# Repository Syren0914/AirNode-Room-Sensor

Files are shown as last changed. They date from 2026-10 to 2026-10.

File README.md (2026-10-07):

# AirNode Room Sensor

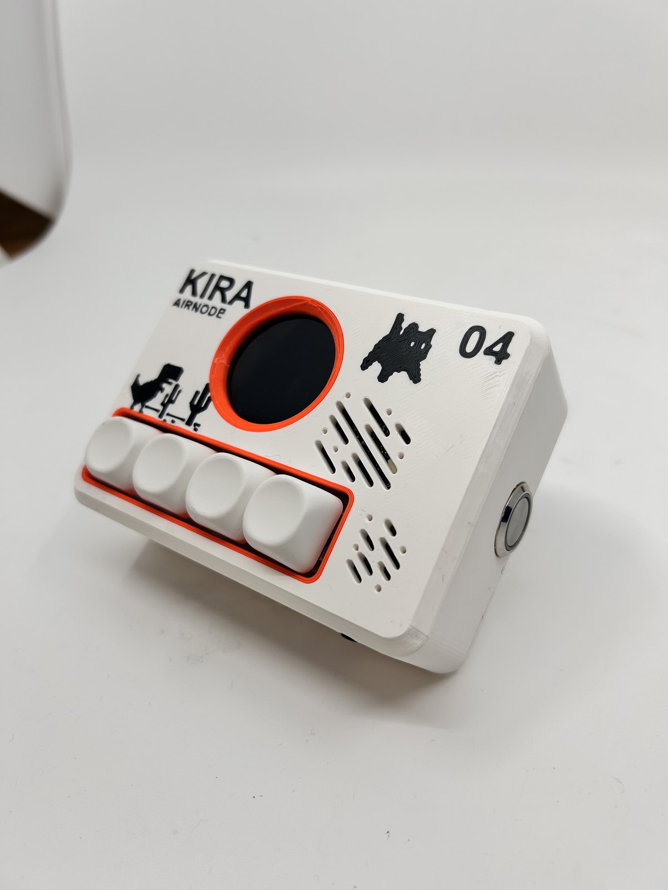
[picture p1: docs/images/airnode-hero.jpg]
AirNode prototype


> [!WARNING]
> **AirNode is an ongoing, unfinished prototype.** The PCB, enclosure, firmware, pin assignments, and documentation may change. This revision has not completed long-term validation, calibration, or product safety testing and is not production ready.

AirNode is an ESP32-C3 based indoor air-quality monitor in a compact 70 mm × 100 mm enclosure. It combines a round color display, four buttons, an audible alarm, and connections for environmental sensor modules.

## Current capabilities

- ESP32-C3 SuperMini with Wi-Fi and Bluetooth LE
- 1.28-inch round SPI TFT
- SHT40 temperature and humidity sensor
- SCD40 carbon-dioxide sensor connection
- SGP41 VOC and NOx sensor connection
- SPS30 particulate-matter sensor connection
- Back-mounted passive piezo buzzer on GPIO20
- Four buttons: Up, Down, Select, and Back
- Two-layer 70 mm × 100 mm PCB with 8 mm corner radii
- 3D-printable enclosure source

## Project status

This repository records a working prototype and the next custom PCB revision. The photographed device uses development modules and point-to-point wiring; the KiCad design consolidates those connections onto a PCB.

| Area | Status |
| --- | --- |
| Schematic ERC | Pass: 0 violations |
| PCB connectivity | Pass: 0 unconnected items |
| PCB DRC | No shorts or clearance violations; one intentional dangling-via warning at the TFT CS layer transition |
| Enclosure | Prototype printed and assembled; PCB fit still requires physical verification |
| Firmware | Working prototype shown; source has not been added to this repository yet |
| Sensor calibration | In progress |
| Production testing | Not started |

## Documentation

- [Hardware and pin assignments](docs/HARDWARE.md)
- [Assembly guide](docs/ASSEMBLY.md)
- [First power-on and validation](docs/BRINGUP.md)
- [Firmware status and requirements](docs/FIRMWARE.md)
- [Enclosure and mechanical fit](docs/ENCLOSURE.md)
- [Board-mounted USB-C power input](docs/USB-C-extension.md)
- [Bill of materials](BOM.csv)
- [Change log](CHANGELOG.md)

## Repository contents

- `Room Sensor.kicad_pro` — KiCad project
- `Room Sensor.kicad_sch` — schematic source
- `Room Sensor.kicad_pcb` — PCB layout source
- `RoomSensor_Libraries/` — project symbols and footprints
- `V.2.3mf` — printable enclosure source
- `Room Sensor.step` — PCB 3D export
- `BOM.csv` — bill of materials
- `manufacturing/gerbers/` — fabrication outputs for the current revision

Open `Room Sensor.kicad_pro` with KiCad 10 or newer. Review the schematic, PCB, and fabrication files together before ordering boards because the project remains under development.

## Prototype gallery

### Assembled enclosure

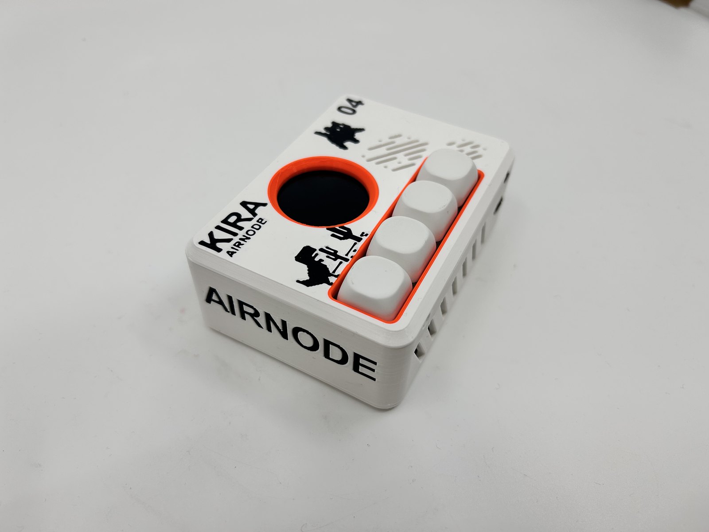
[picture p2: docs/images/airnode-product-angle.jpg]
AirNode enclosure prototype


### Working development prototype

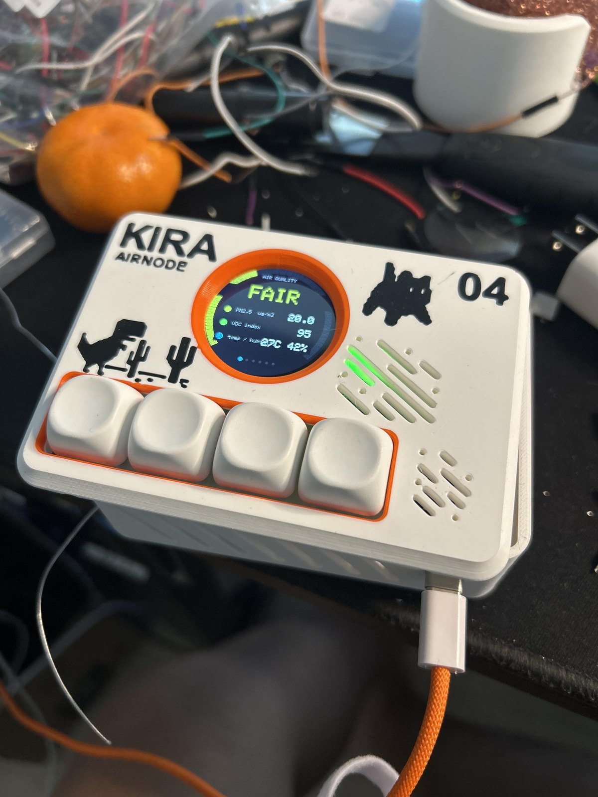
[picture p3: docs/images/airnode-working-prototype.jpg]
AirNode displaying live sensor data


### Internal development build

These photos show development wiring and module placement. They do not represent the final PCB assembly.

| Open prototype | Assembly in progress |
| --- | --- |
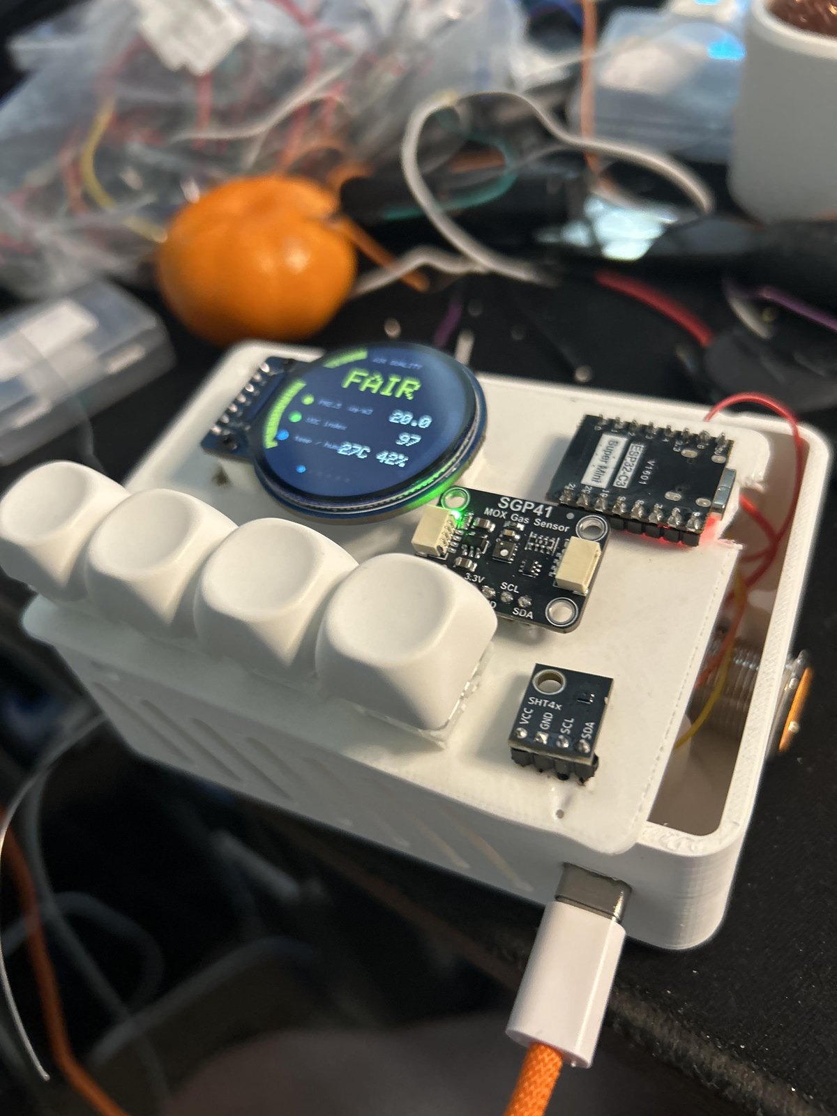
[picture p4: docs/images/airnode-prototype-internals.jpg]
Open AirNode prototype
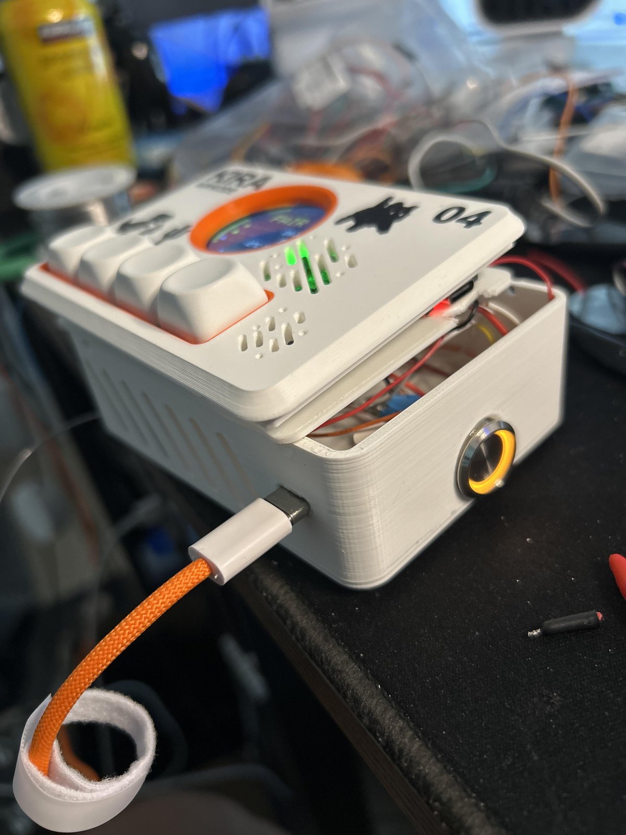
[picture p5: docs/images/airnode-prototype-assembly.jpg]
AirNode assembly in progress
|  |  |

## Enclosure files

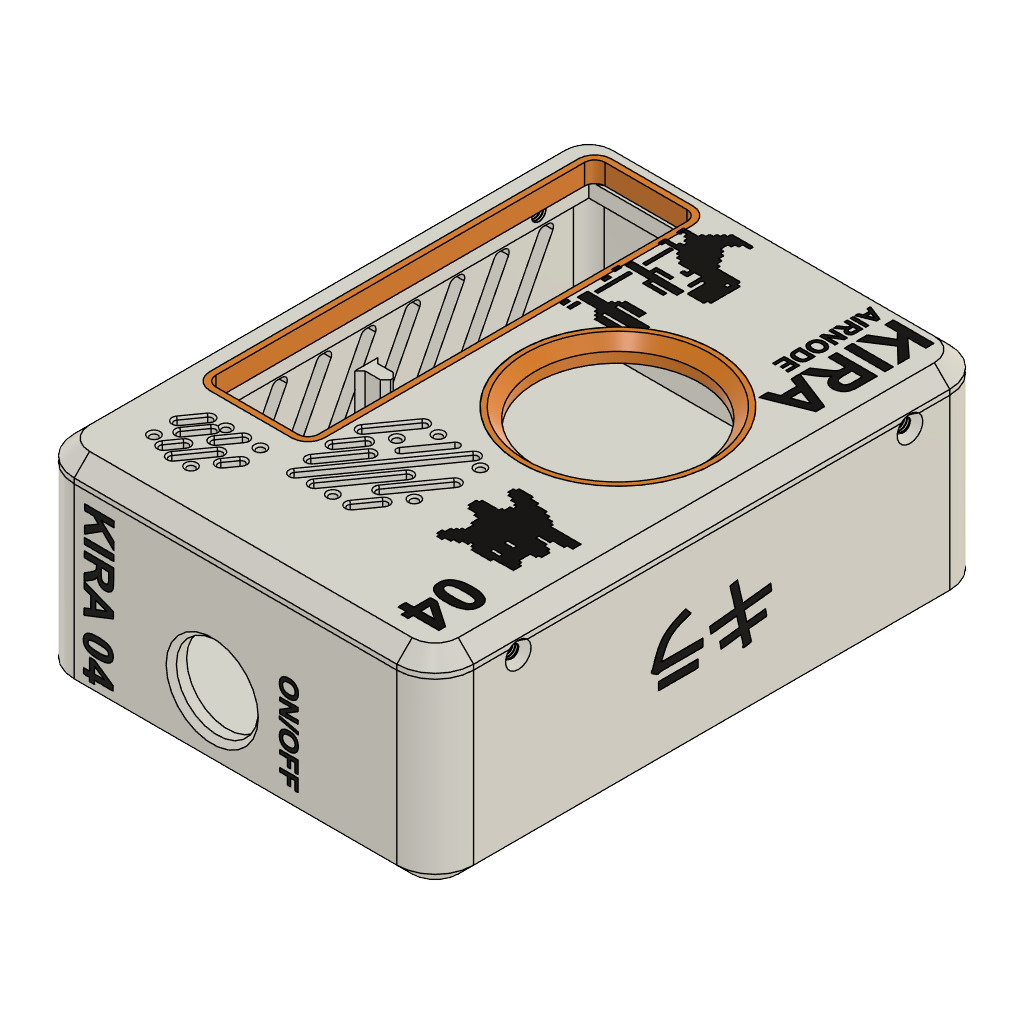
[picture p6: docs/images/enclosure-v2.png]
AirNode enclosure render


[Download `V.2.3mf`](V.2.3mf)

## Before building

1. Read the [hardware notes](docs/HARDWARE.md) and confirm that your modules match the listed pin order and voltage.
2. Verify the exact dimensions and pad spacing of every purchased breakout board. Visually similar modules often differ.
3. Inspect the fabrication files and run ERC and DRC with your installed KiCad version.
4. Assemble and test one prototype before ordering multiple boards.
5. Follow the staged checks in the [bring-up guide](docs/BRINGUP.md).

## License

Hardware design files are released under the CERN Open Hardware Licence Version 2 — Strongly Reciprocal. See [LICENSE](LICENSE).

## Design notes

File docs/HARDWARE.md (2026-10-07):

# Hardware reference

> **Development status:** this document describes the current unfinished PCB revision. Confirm every connection against the KiCad schematic before assembly.

## Board

- Size: 70 mm × 100 mm
- Corner radius: 8 mm
- Copper layers: front and back
- Controller: ESP32-C3 SuperMini module
- Supply input: nominal 5 V through board-mounted `J_USB` and the latching switch, or through the SuperMini USB-C socket during development
- Logic voltage: 3.3 V

## ESP32-C3 pin assignment

| GPIO | Function |
| --- | --- |
| GPIO0 | TFT clock (`TFT_SCL`) |
| GPIO1 | TFT data / MOSI (`TFT_SDA`) |
| GPIO2 | TFT data/command (`DC`), with a 10 kΩ pull-up to 3.3 V |
| GPIO3 | I²C clock (`SCL`) |
| GPIO4 | I²C data (`SDA`) |
| GPIO5 | Up button |
| GPIO6 | TFT chip select (`CS`) |
| GPIO7 | TFT reset (`RST`) |
| GPIO8 | Unused in this revision |
| GPIO9 | Select button |
| GPIO10 | Back button |
| GPIO20 | Passive piezo buzzer |
| GPIO21 | Down button |

GPIO9 is a boot strapping pin on the ESP32-C3. Avoid holding Select while resetting or powering the board unless intentionally entering the associated boot state.

## Module connectors

Connector numbering follows the symbols and footprints in this repository. Check the labels printed on the module you own before plugging it in.

| Module | Pin 1 | Pin 2 | Pin 3 | Pin 4 | Pin 5 |
| --- | --- | --- | --- | --- | --- |
| TFT1 | RST | CS | DC | MOSI | SCK |
| TFT1 continued | Pin 6: GND | Pin 7: 5 V |  |  |  |
| SHT40 | SENSOR_3V3 | GND | SCL | SDA | — |
| SCD40 | SENSOR_3V3 | GND | SCL | SDA | — |
| SGP41 | SDA | SCL | GND | NC | SENSOR_3V3 |
| SPS30 | 5 V | SDA | SCL | GND | GND |

SHT40, SCD40, and SGP41 share the I²C bus. Confirm that the breakout modules contain any required pull-up resistors and that the combined pull-up resistance is suitable. Do not feed 5 V logic into the ESP32-C3 pins.

## Sensor power link

JP1 connects `SENSOR_3V3` to the board's 3.3 V rail. Install the specified insulated wire link or jumper before expecting the SHT40, SCD40, or SGP41 headers to receive power. Check for shorts before installing it.

## Buttons and alarm

SW1 through SW4 connect their GPIO signal to ground when pressed. Firmware should enable an internal pull-up for each button. BZ1 is a passive piezo element connected between GPIO20 and ground; drive it with PWM or a tone waveform. Check the selected buzzer's current requirement before direct GPIO drive. Add a transistor driver if it exceeds the ESP32-C3 GPIO rating.

## Mechanical placement

- TFT1 is positioned for the enclosure face and was moved 1 mm right and 2 mm upward from the earlier layout.
- BZ1 is mounted on the back of the PCB.
- SHT40 is on the front near the board edge for ambient-air exposure.
- SCD40 is mounted on the back with clearance from the SHT40 area.
- The module outlines still require verification with the exact purchased parts.

## USB-C power and programming

`J_USB` is a GCT USB4125-03-C power-only receptacle mounted on the rear lower edge. Its two CC pins each use a 5.1 kOhm pull-down (`R_CC1` and `R_CC2`) so a USB-C source enables 5 V. Raw VBUS goes to `J_PWR` pads 1 and 2. The latching switch connects pad 2 (COM) to pad 3 (NO), and pad 3 feeds the board `VIN (5.0v)` net. Pad 4 is ground and LED−.

The six-contact USB4125 does not contain D+ or D− contacts. The current SuperMini footprint also does not expose GPIO18/19, so firmware flashing remains through the USB-C socket on the ESP32-C3 SuperMini itself.

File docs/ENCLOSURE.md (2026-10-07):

# Enclosure and mechanical fit

The current enclosure is provided as [`V.2.3mf`](../V.2.3mf). It is a development model and may change with the PCB and module selection.

AirNode enclosure prototype

## Alignment method

Use the PCB mounting holes and `Edge.Cuts` outline as the shared datum between KiCad and CAD. Import [`Room Sensor.step`](../Room%20Sensor.step) into the enclosure assembly and constrain those mounting features before adjusting openings.

For the round TFT:

1. Model the complete TFT module, including its PCB, header, display rim, and solder joints.
2. Align the module to the PCB footprint rather than centering only the visible circle.
3. Keep a small printable clearance around the display rim and test the opening with a thin front-panel slice.
4. Verify the viewing area with the screen powered before printing the full enclosure.

The current PCB places TFT1 1 mm to the right and 2 mm upward relative to the earlier layout.

## USB-C opening

`J_USB` is a GCT USB4125-03-C receptacle mounted on the rear of the PCB at the lower board edge. The footprint places the connector mating edge on the 100 mm board boundary. Match the enclosure opening to the manufacturer drawing and verify the first assembled board before printing a production enclosure batch.

Provide clearance for:

- the metal plug shell and cable overmold
- breakout-board thickness and solder joints
- the internal cable bend
- insertion force without loading the PCB

## Airflow

An additional enclosure fan is not recommended for the current design. The SPS30 includes its own airflow system, while forced air and fan heat can disturb the SHT40 and SCD40 readings. Use passive vents around the environmental sensors and keep the inlet and outlet paths open.

Keep dust out through sensible vent orientation and periodic cleaning. A dense filter can restrict particulate sampling and should only be added after measurement testing.

## Fit checklist

- PCB clears every wall, post, screw head, and wire.
- TFT is centered in the front opening.
- Buttons move freely without constant preload.
- SHT40 and SCD40 have separate, unobstructed air space.
- Buzzer does not touch the TFT or enclosure.
- USB-C plug inserts fully.
- SPS30 airflow is not recirculated.
- No vent exposes an accidental finger path to sharp solder joints.

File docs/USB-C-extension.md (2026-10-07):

# Board-mounted USB-C power input

## Implemented connector

The PCB now carries `J_USB`, a GCT USB4125-03-C USB-C receptacle, on the rear lower edge. It is a six-contact, power-only receptacle with VBUS, GND, CC1, and CC2 contacts. Its footprint is `Connector_USB:USB_C_Receptacle_GCT_USB4125-xx-x_6P_TopMnt_Horizontal`.

`R_CC1` and `R_CC2` are separate 5.1 kOhm, 1% 0805 pull-downs from CC1 and CC2 to ground. Do not join the two CC pins directly.

## Latching power switch

The enclosure uses a 16 mm push-on/push-off latching switch with a 3–6 V LED ring. Wire it to `J_PWR` as follows:

| J_PWR pad | Connection |
| --- | --- |
| 1 | Raw VBUS from `J_USB` |
| 2 | Switch COM |
| 3 | Switch NO and LED+ |
| 4 | GND and LED− |

Pads 1 and 2 are linked by the PCB. When the switch latches, pad 3 receives 5 V and feeds the board `VIN (5.0v)` net. The LED ring therefore lights only while AirNode is powered. Leave the switch NC terminal unused. Verify COM, NO, NC, LED+, and LED− with the switch drawing or a continuity meter because terminal positions vary.

## Programming limitation

`J_USB` is power-only and cannot carry firmware data. The USB4125-03-C has no D+ or D− contacts, and the current ESP32-C3 SuperMini footprint does not expose its native USB pins GPIO18 and GPIO19. Program and monitor the board through the USB-C socket on the SuperMini.

## First-board checks

1. Inspect the USB shell tabs and six signal pads for solder bridges.
2. Confirm each CC pin measures approximately 5.1 kOhm to GND.
3. With the switch off, confirm `J_USB` VBUS reaches `J_PWR` pads 1 and 2 but not pad 3.
4. Latch the switch on and confirm pad 3 and ESP32 5 V receive power.
5. Confirm the LED ring polarity and that it turns off when the switch opens.
6. Test firmware flashing through the SuperMini socket before closing the enclosure.

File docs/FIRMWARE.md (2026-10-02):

# Firmware

## Status

Firmware source has **not yet been added to this repository**. The prototype photos show working development firmware, but the project remains ongoing and unfinished. Add the source, build instructions, dependencies, and release binaries before publishing a reproducible hardware release.

## Current hardware interface

The firmware must support:

- SPI display signals on GPIO0, GPIO1, GPIO2, GPIO6, and GPIO7
- I²C sensors on GPIO3 (SCL) and GPIO4 (SDA)
- Buttons on GPIO5, GPIO21, GPIO9, and GPIO10 using pull-ups
- Passive buzzer output on GPIO20
- Wi-Fi configuration and server communication, if enabled

See [HARDWARE.md](HARDWARE.md) for the complete pin table.

## Recommended repository layout

When the firmware is published, place it in a top-level `firmware/` directory with:

- source code and configuration files
- the exact ESP32 board/core version
- dependency names and pinned versions
- build and flashing commands
- a sample configuration without secrets
- license information
- a documented data format and server endpoint configuration

Never commit Wi-Fi passwords, API keys, private certificates, or server credentials.

## Required behavior

- Detect absent sensors without locking the user interface.
- Debounce all four buttons.
- Avoid treating GPIO9 as pressed during normal boot.
- Rate-limit the buzzer and provide a way to silence alarms.
- Display a clear sensor fault when readings are unavailable or stale.
- Store calibration baselines only as recommended by each sensor manufacturer.
- Retry network operations without blocking sensor sampling or the local controls.

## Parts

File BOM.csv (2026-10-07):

Reference | Qty | Description | Value or model | Footprint or connection | Status | Notes
U2 | 1 | Wi-Fi/BLE microcontroller module | ESP32-C3 SuperMini | ESP32-C3_SUPERMINI_TH:MODULE_ESP32-C3_SUPERMINI_TH | Required | Current module USB port remains the programming interface
TFT1 | 1 | 1.28-inch round SPI TFT display | GC9A01 240x240 | 1x7 2.54 mm header | Required | Confirm the purchased module pin order and physical outline
SHT40 | 1 | Temperature and humidity breakout | SHT40 module | 1x4 2.54 mm header | Required | Front-side module
SCD40 | 1 | Photoacoustic CO2 breakout | SCD40 module | 1x4 2.54 mm header | Optional | Back-side module; SCD41 is generally pin-compatible but firmware settings may differ
SGP41 | 1 | VOC and NOx breakout | SGP41 module | 1x5 2.54 mm header | Required | Use 3.3 V compatible breakout
SPS30 | 1 | Particulate-matter sensor | Sensirion SPS30 | 1x5 2.54 mm header | Required | Confirm cable pin order against the sensor datasheet
BZ1 | 1 | Passive piezo buzzer | 12 mm diameter 7.6 mm lead spacing | Buzzer_Beeper:Buzzer_12x9.5RM7.6 | Required | Mounted on back; use passive piezo suitable for 3.3 V drive
SW1 SW2 SW3 SW4 | 4 | Momentary push button | Cherry MX compatible | SW_Cherry_MX_1.00u_PCB | Required | Up Down Select Back
R1 | 1 | Through-hole resistor | 10 kOhm 1/4 W | DIN0207 7.62 mm pitch | Required | GPIO2 boot pull-up
JP1 | 1 | Insulated wire link | 12.70 mm pitch | Wire_Link_P12.70mm | Required | Install insulated jumper wire
H1 H2 | 2 | M3 mounting hole | 3.2 mm drill | MountingHole_3.2mm_M3 | Required | Use enclosure-compatible hardware
J_USB | 1 | Board-mounted USB-C power receptacle | GCT USB4125-03-C | Connector_USB:USB_C_Receptacle_GCT_USB4125-xx-x_6P_TopMnt_Horizontal | Required | Rear side at lower PCB edge; power-only connector without D+ or D- contacts
R_CC1 R_CC2 | 2 | USB-C CC pull-down resistor | 5.1 kOhm 1% | Resistor_SMD:R_0805_2012Metric | Required | One resistor from each CC pin to GND
SW-PWR | 1 | Illuminated latching power switch | 16 mm push-on push-off switch with 3-6 V LED ring | PCB J_PWR pads 2 3 4 | Required | COM to pad 2; NO and LED+ to pad 3; LED- to pad 4; verify terminal pinout
J_PWR | 1 | USB and latching-switch wiring header | 1x04 2.54 mm through-hole | Back side near lower edge | Required | Pad 1 raw USB VBUS; pad 2 switch COM; pad 3 switch NO and LED+; pad 4 GND and LED-
PCB | 1 | Two-layer printed circuit board | 70 x 100 mm 8 mm corner radius | Project Gerbers | Required | Prototype may be CNC milled or fabricated
ENC1 | 1 | Printed enclosure | V.2.3mf | FDM printed | Required | Verify port and display alignment with a physical test print

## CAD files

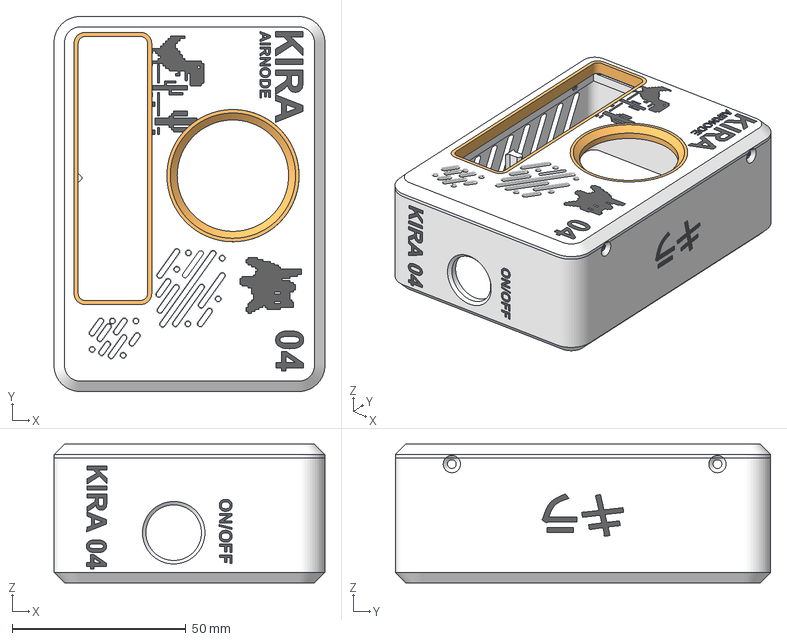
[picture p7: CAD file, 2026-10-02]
V.2.3mf
78.0 x 108.0 x 40.0 mm
BOTTOM (1)
BOTTOM
Keycap ring

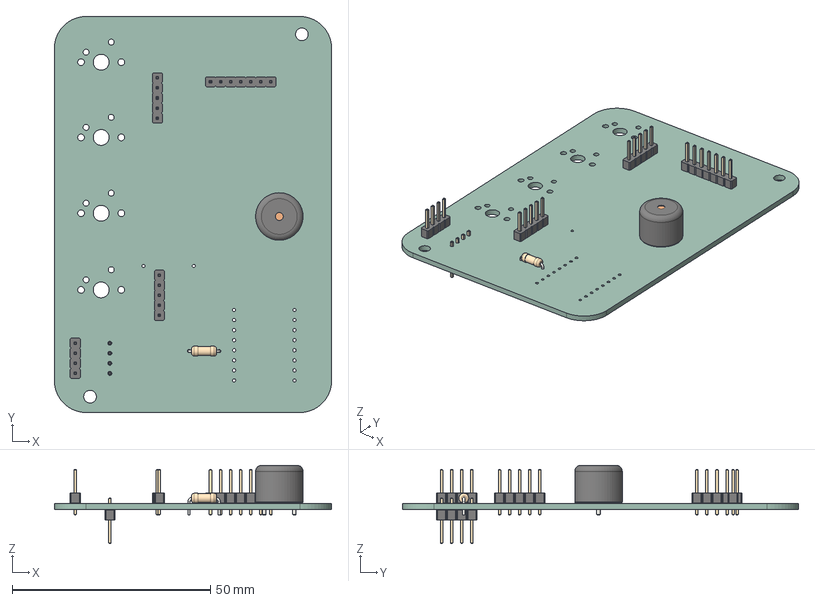
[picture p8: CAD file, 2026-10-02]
Room Sensor.step
70.0 x 100.0 x 19.8 mm
Buzzer_12x95RM76
PinHeader_1x07_P254mm_Vertical
PinHeader_1x05_P254mm_Vertical x 2
R_Axial_DIN0207_L63mm_D25mm_P762mm_Horizontal
PinHeader_1x04_P254mm_Vertical x 2
Roo8774_PCB

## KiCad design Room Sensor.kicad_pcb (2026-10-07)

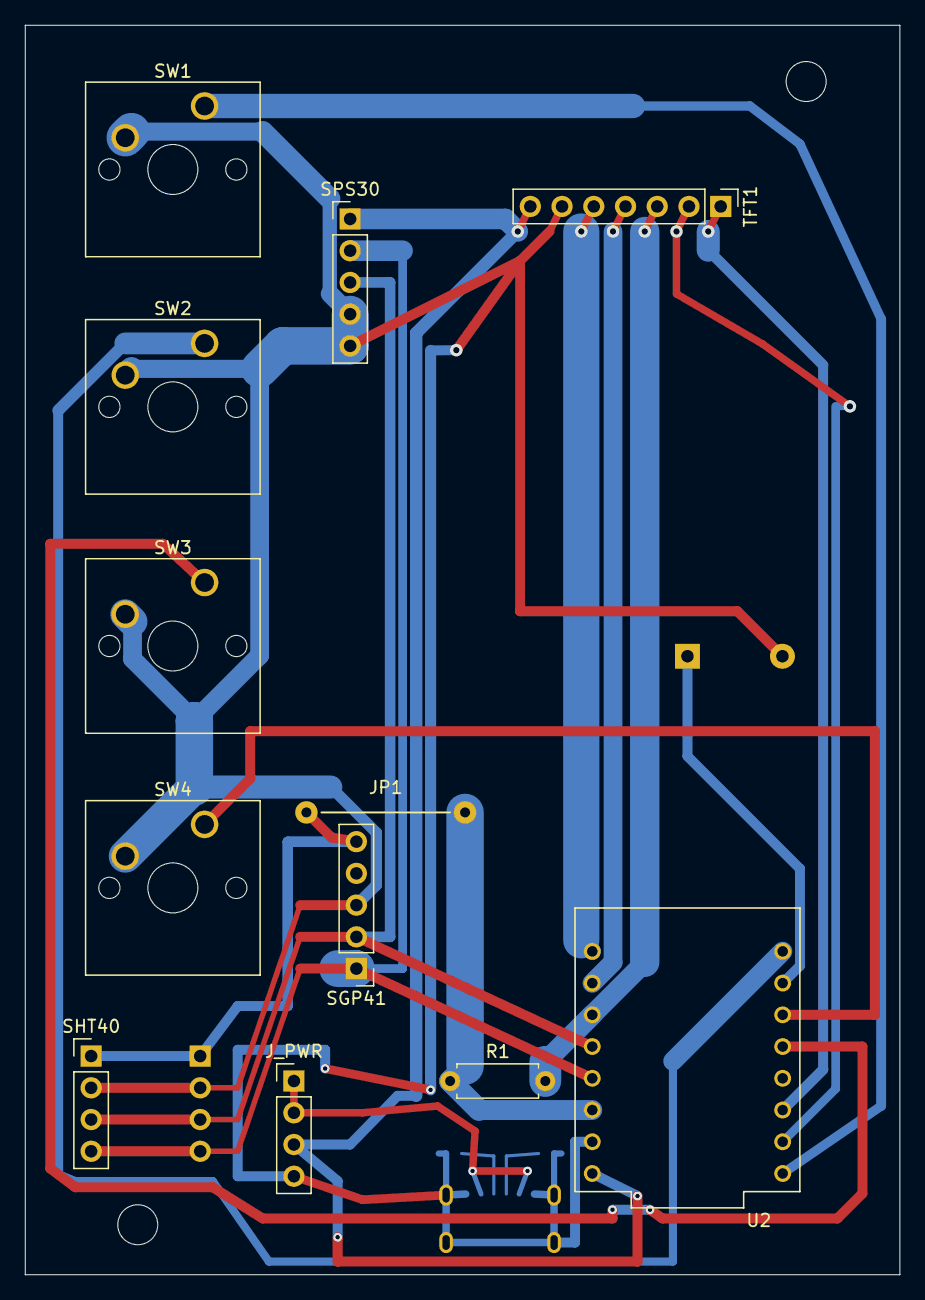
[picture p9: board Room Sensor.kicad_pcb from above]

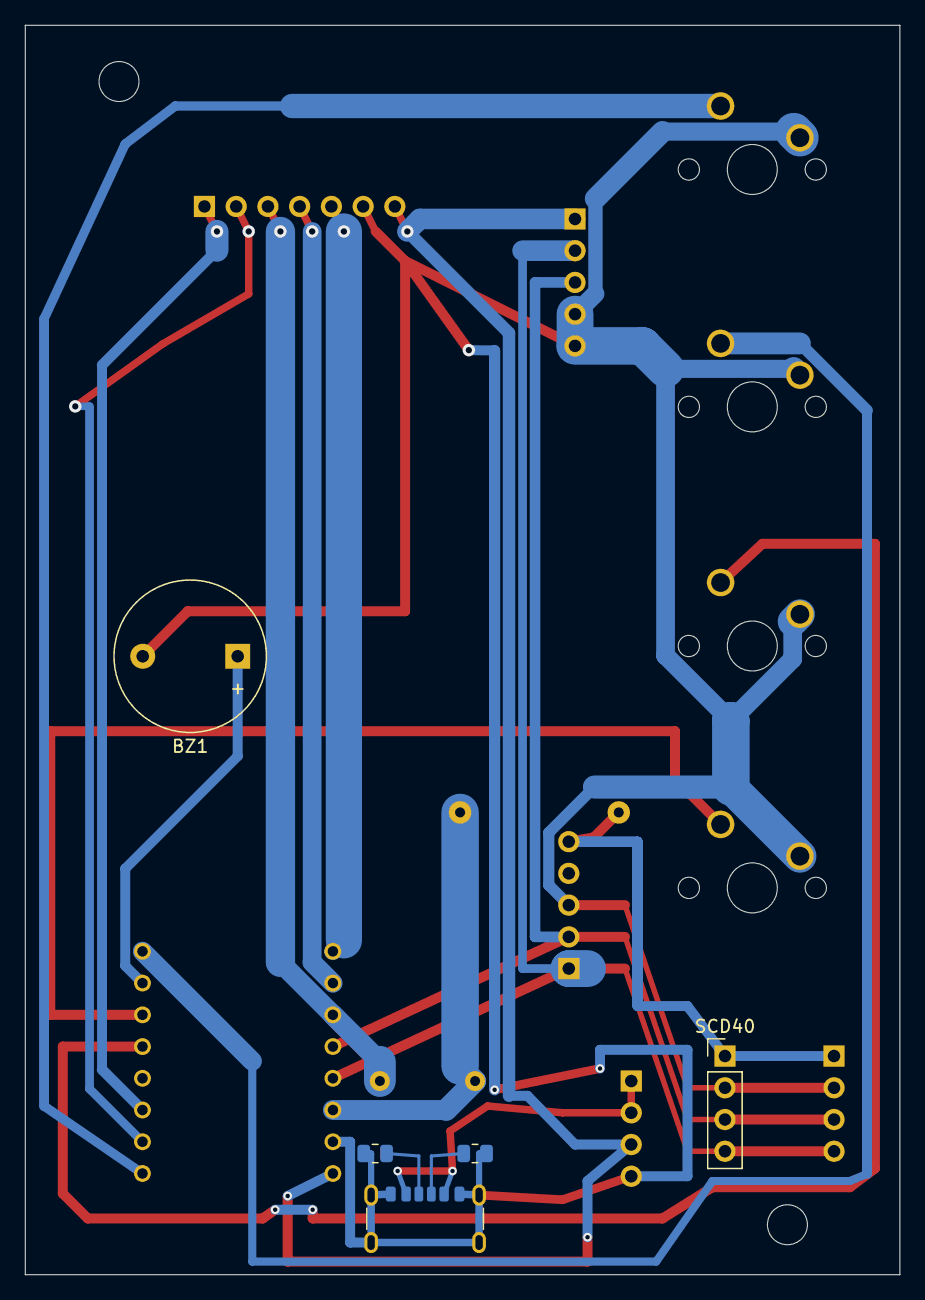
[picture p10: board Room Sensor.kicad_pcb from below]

Board: 2 copper layers, 70.0 x 100.0 mm, 19 parts (6 on the bottom side), 19 nets.

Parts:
BZ1: Piezo Buzzer; Buzzer_12x9.5RM7.6
H1, H2: MountingHole_3.2mm_M3
JP1: INSULATED WIRE; Wire_Link_P12.70mm
J_PWR: USB5V_SW_COM_SW_NO_GND; PinHeader_1x04_P2.54mm_Vertical
J_USB: GCT USB4125-03-C USB-C Power Input; USB_C_Receptacle_GCT_USB4125-xx-x_6P_TopMnt_Horizontal
R1: 10k; R_Axial_DIN0207_L6.3mm_D2.5mm_P7.62mm_Horizontal
R_CC1, R_CC2: 5.1k; R_0805_2012Metric
SCD40: SCD40 I2C; PinHeader_1x04_P2.54mm_Vertical
SGP41: Conn_01x05; PinHeader_1x05_P2.54mm_Vertical
SHT40: Conn_01x04; PinHeader_1x04_P2.54mm_Vertical
SPS30: Conn_01x05; PinHeader_1x05_P2.54mm_Vertical
SW1, SW2, SW3, SW4: SW_Push; SW_Cherry_MX_1.00u_PCB
TFT1: Conn_01x07; PinHeader_1x07_P2.54mm_Vertical
U2: ESP32-C3_SUPERMINI_TH; MODULE_ESP32-C3_SUPERMINI_TH

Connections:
/BTN_BACK: SW4.1, U2.10 (GPIO10)
/BTN_DOWN: SW2.1, U2.21 (GPIO21)
/BTN_SELECT: SW3.1, U2.9 (GPIO9)
/BTN_UP: SW1.1, U2.5 (GPIO5)
/BUZZER: BZ1.1, U2.20 (GPIO20)
/CS: TFT1.2, U2.6 (GPIO6)
/DC: R1.2, TFT1.3, U2.2 (GPIO2)
/GND: BZ1.2, J_PWR.4, J_USB.A12, J_USB.B12, J_USB.SH, R_CC1.2, R_CC2.2, SCD40.2, SGP41.3, SHT40.2, SPS30.4, SPS30.5, SW1.2, SW2.2, SW3.2, SW4.2, TFT1.6, U2.G (GND)
/RST: TFT1.1, U2.7 (GPIO7)
/SCL: SCD40.3, SGP41.2, SHT40.3, SPS30.3, U2.3 (GPIO3)
/SDA: SCD40.4, SGP41.1, SHT40.4, SPS30.2, U2.4 (GPIO4)
/SENSOR_3V3: JP1.1, SCD40.1, SGP41.5, SHT40.1
/TFT_SCL: TFT1.5, U2.0 (GPIO0)
/TFT_SDA: TFT1.4, U2.1 (GPIO1)
/USB_CC1: J_USB.A5, R_CC1.1
/USB_CC2: J_USB.B5, R_CC2.1
/USB_VBUS_RAW: J_PWR.1, J_PWR.2, J_USB.A9, J_USB.B9
/VCC (3.3v): JP1.2, R1.1, U2.3.3 (3V3)
/VIN (5.0v): J_PWR.3, SPS30.1, TFT1.7, U2.5V

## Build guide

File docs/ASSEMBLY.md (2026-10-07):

# Assembly guide

This guide is for prototype assembly. The project is unfinished, so inspect the latest schematic and PCB before soldering.

## Required preparation

- Compare the purchased modules with [BOM.csv](../BOM.csv).
- Measure header pitch, board width, board length, connector overhang, and mounting holes. Similar breakout boards may use different layouts.
- Print the PCB and enclosure drawings at 100% scale or use a low-cost test PCB before committing to a full batch.
- Confirm the front/back orientation of each connector and module.

## Suggested assembly order

1. Inspect the bare PCB for shorts, incomplete milling, burrs, or damaged plating.
2. Install low-profile resistors, jumper JP1, and small connectors.
3. Check resistance between 5 V and ground and between 3.3 V and ground.
4. Install the ESP32-C3 SuperMini headers or sockets.
5. Install the TFT connector and four button switches.
6. Mount the SHT40 on the front and the SCD40 and buzzer on the back, following the PCB markings.
7. Install SGP41 and SPS30 connectors if those sensors will be used.
8. Solder `J_USB`, `R_CC1`, and `R_CC2`, then wire the illuminated latching power switch to `J_PWR` according to [USB-C-extension.md](USB-C-extension.md). Verify the switch terminals with a continuity meter because terminal positions vary by manufacturer.
9. Perform the staged tests in [BRINGUP.md](BRINGUP.md) before closing the enclosure.

## Home-milled PCB notes

- Use the widest traces and clearances that the design and cutter allow.
- Verify isolation around every pad with a magnifier and continuity meter.
- Remove copper burrs before inserting modules.
- A double-sided home-milled board does not automatically plate through-holes. Solder accessible vias on both sides or install wire rivets where required.
- Confirm that vias hidden beneath a module can be completed before mounting that module.
- Avoid relying on the solder mask shown in KiCad because a milled board may not have one.

## Sensor handling

- Keep flux, glue, conformal coating, solvents, and fingerprints away from exposed sensor openings.
- Do not place the SHT40 beside warm regulators or the ESP32 antenna area.
- Keep the SCD40 air opening unobstructed.
- Keep the SPS30 inlet and outlet paths open; it contains its own fan.
- Allow the assembled device to reach room temperature before evaluating readings.

## Enclosure installation

Dry-fit the unpowered PCB first. Confirm button travel, screen centering, USB-C insertion, wiring bend radius, buzzer clearance, and unobstructed vents. Do not force the PCB against a module or cable.

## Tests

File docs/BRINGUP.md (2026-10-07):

# Prototype bring-up

Use a current-limited bench supply when possible. Stop if a component heats unexpectedly or the supply immediately reaches its current limit.

## 1. Unpowered checks

- Inspect both copper layers for bridges and incomplete isolation.
- Check continuity from each supply pin to its intended rail.
- Confirm there is no short from 5 V to ground or 3.3 V to ground.
- Confirm JP1 is installed only after the sensor rail has been checked.
- Check that each button shorts its signal to ground only while pressed.

## 2. Controller-only power test

1. Remove plug-in sensor modules if sockets are used.
2. Apply 5 V with a conservative current limit.
3. Verify the board's 3.3 V rail before fitting sensors.
4. Confirm the ESP32-C3 can be detected and programmed through the SuperMini's own USB-C socket.
5. Disconnect power and investigate any abnormal current or heating.

## 3. Peripheral tests

Add and test one subsystem at a time:

1. TFT: verify reset, chip select, command/data, clock, and MOSI.
2. Buttons: verify Up, Down, Select, and Back individually. Remember that Select uses GPIO9.
3. Buzzer: begin with a short, low-duty PWM tone.
4. SHT40: scan the I²C bus, then compare temperature and humidity with a reference.
5. SCD40: allow warm-up and verify plausible CO₂ readings in fresh indoor air.
6. SGP41: follow the sensor library's conditioning and compensation requirements.
7. SPS30: verify clear inlet/outlet airflow and plausible particulate readings.

## 4. Enclosure test

- Run the assembled unit with the cover installed and log readings over several hours.
- Compare covered and uncovered SHT40 temperature to detect self-heating.
- Check that SCD40 readings respond when occupied air reaches the vents.
- Check that the SPS30 exhaust does not recirculate directly into its inlet.
- Confirm that `J_USB` powers the board in both plug orientations. Use the SuperMini USB-C socket for programming.

## 5. Release checks still required

Before calling a revision complete, record the tested module part numbers, verify enclosure tolerances, repeat ERC/DRC, test every manufactured board, validate sensor calibration, and perform long-duration power and thermal testing.

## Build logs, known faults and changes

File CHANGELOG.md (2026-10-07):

# Change log

This project is under active development. Entries describe design progress and do not imply a production release.

## Unreleased

- Added a rear, board-mounted GCT USB4125-03-C USB-C power receptacle with dual 5.1 kOhm CC pull-downs and rerouted the latching-switch power path.
- Documented that firmware flashing remains on the ESP32-C3 SuperMini USB-C socket.

- Added a two-layer 70 mm × 100 mm PCB outline with 8 mm corner radii.
- Increased trace widths for home PCB fabrication where routing clearance permits.
- Added a passive piezo buzzer on GPIO20 and moved it to the back of the PCB.
- Assigned the Select button to GPIO9.
- Added SCD40 CO₂ and other environmental sensor connections.
- Adjusted SHT40 and SCD40 placement for module clearance.
- Moved TFT1 1 mm right and 2 mm up for enclosure alignment.
- Rerouted copper around the relocated lower mounting hole.
- Added fabrication outputs, BOM, enclosure source, prototype photos, and build documentation.
- Documented the external USB-C programming extension.

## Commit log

2026-10-02 Publish AirNode room sensor hardware
    [BOM.csv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]
2026-10-02 Add enclosure previews to README
2026-10-02 Remove cover insert model
    [cover.3mf]
2026-10-02 Add comprehensive prototype documentation
2026-10-02 Document latching USB-C power switch
    [BOM.csv]
2026-10-02 Add KiCad latching USB power interface
    [BOM.csv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]
2026-10-07 Add board-mounted USB-C power input
    [BOM.csv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]
2026-10-12 Complete PCB manufacturing audit
